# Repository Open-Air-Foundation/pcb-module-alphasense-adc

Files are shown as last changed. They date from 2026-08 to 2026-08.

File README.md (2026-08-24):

# AirGradient AlphaSense ADC Module — Hardware

> KiCad hardware design files for the AirGradient AlphaSense ADC module — the interface board that digitizes the AlphaSense electrochemical gas sensors in the [Open Air Max](https://www.airgradient.com/professional/products/open-air-max/) outdoor air quality monitor.

## Overview

A compact 2-layer board carrying two Texas Instruments ADS1115 16-bit ADCs that read the AlphaSense electrochemical sensors — NO₂ (A43F) and O₃ (A431) — and report to the host monitor over I²C. The supply is filtered through a ferrite bead for clean analog readings.

## Design structure

A single KiCad project in `alphasense-adc/`: one schematic sheet and a 2-layer board. (The project was originally named "ADS1115 for AlphaSense NO2-O3", published on Bitbucket as `alphasense-oa-pcb`, and renamed `alphasense-adc` here; the Gerber filenames inside the archived production zip keep the `alphasense-oa-pcb` naming.)

## Repository structure

```
alphasense-adc/           # KiCad project (schematic + board), production/
libraries/                   # Bundled 3D model libraries
```

## Key components

| Function | Part | Ref |
|---|---|---|
| 16-bit I²C ADC | TI ADS1115IDGSR | U1–U2 |
| Supply filter (ferrite bead) | MMZ2012Y152BT000 | FB1 |
| Host connector (1.25 mm, 8-pin) | Molex 53261-0871 | J1, CN1 |
| Sensor header (2×5 IDC, 2.54 mm) | AWHW2-10G | J2 |

## Toolchain

- **KiCad 9** (file format 2024-12). Symbols and footprints are embedded in the design files; bundled 3D models are referenced project-relative — the project opens without any extra library setup.
- **[Fabrication Toolkit](https://github.com/bennymeg/Fabrication-Toolkit)** plugin — generates the Gerber/BOM/CPL production set in JLCPCB-compatible format.
- Active DRC rules are in `alphasense-adc/alphasense-adc.kicad_dru`.

## Fabrication

`alphasense-adc/production/` holds the ready-to-order set: Gerber zip, BOM, designators, and pick-and-place positions (generated with Fabrication Toolkit, LCSC part numbers for assembly at JLCPCB).

## Versioning & releases

Hardware revisions are tagged on this repository. Per-version release notes and the matching production file set are published on the [GitHub Releases](../../releases) page.

## License

This is open-source hardware. The design files in this repository are licensed under the
[Creative Commons Attribution-ShareAlike 4.0 International (CC BY-SA 4.0)](https://creativecommons.org/licenses/by-sa/4.0/) license — see [LICENSE](LICENSE).

You are free to use, modify, and manufacture these designs, including commercially, provided you credit AirGradient and share derivative designs under the same license.

## Maintainers

AirGradient hardware team.

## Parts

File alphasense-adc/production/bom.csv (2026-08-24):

Designator | Footprint | Quantity | Value | LCSC Part #
C1, C2 | CAPC1608X90N | 2 | CL10B105KP8NNNC
CN1 | CONN-SMD_532610871 | 1 | 532610871 | C293349
FB1 | BEADC2012X105N | 1 | MMZ2012Y152BT000
J2 | AWHW210G0202TR | 1 | AWHW2-10G-0202-T-R
R3, R8 | RESC1608X55N | 2 | 10K
R4, R5, R6, R7 | RESC1608X55N | 4 | 1K
U1, U2 | SOP50P490X110-10N | 2 | ADS1115IDGSR

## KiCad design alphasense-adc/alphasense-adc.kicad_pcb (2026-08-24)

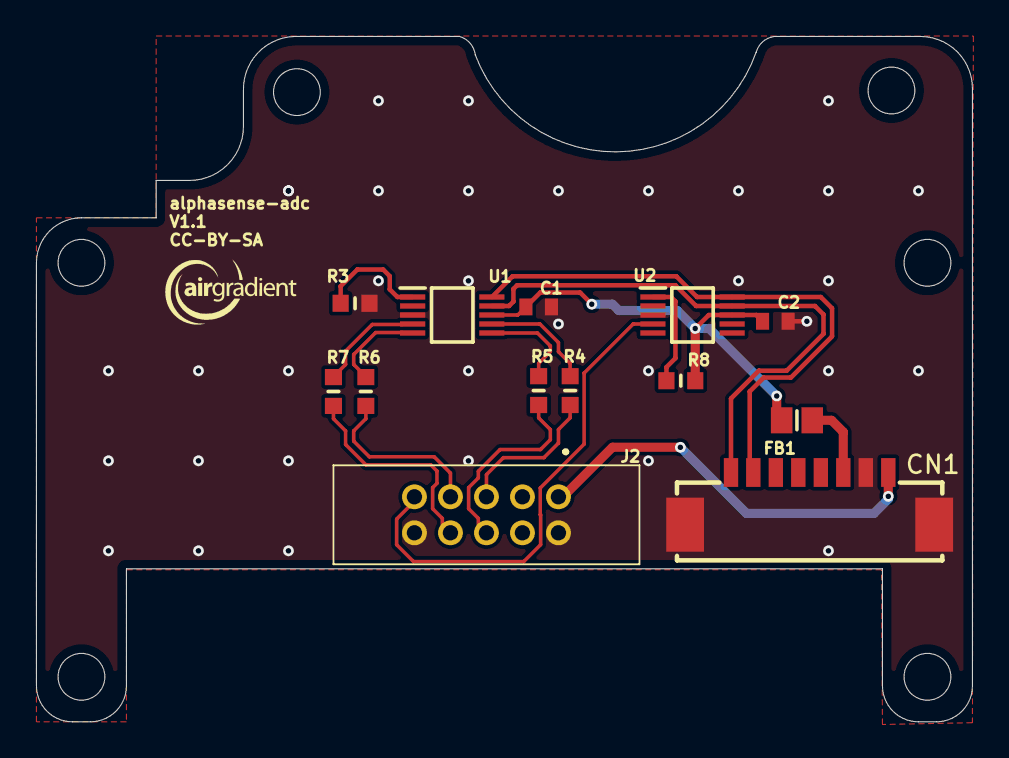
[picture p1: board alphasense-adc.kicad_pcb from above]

Board: 2 copper layers, 52.0 x 38.1 mm, 13 parts (0 on the bottom side), 17 nets.

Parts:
C1, C2: CL10B105KP8NNNC; CAPC1608X90N
CN1: 532610871; CONN-SMD_532610871
FB1: MMZ2012Y152BT000; BEADC2012X105N
J2: AWHW2-10G-0202-T-R; AWHW210G0202TR
R3, R8: 10K; RESC1608X55N
R4, R5, R6, R7: 1K; RESC1608X55N
U1, U2: ADS1115IDGSR; SOP50P490X110-10N

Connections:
3V3: C1.1, C2.1, FB1.2, R8.1, U1.8 (VDD), U2.8 (VDD)
5V: CN1.8, J2.1
+3.3V: CN1.6, FB1.1
/PT1000: J2.9, U2.4 (AIN0)
/SCL: CN1.2, U1.10 (SCL), U2.10 (SCL)
/SDA: CN1.1, U1.9 (SDA), U2.9 (SDA)
/SN1+: J2.8, R7.2
/SN1-: J2.7, R6.2
/SN1_N: R6.1, U1.5 (AIN1)
/SN1_P: R7.1, U1.4 (AIN0)
/SN2+: J2.6, R5.1
/SN2-: J2.5, R4.2
/SN2_N: R4.1, U1.7 (AIN3)
/SN2_P: R5.2, U1.6 (AIN2)
GND: C1.2, C2.2, CN1.0, CN1.7, J2.2, J2.10, R3.2, U1.3 (GND), U2.3 (GND)
unnamed: R3.1, U1.1 (ADDR)
unnamed: R8.2, U2.1 (ADDR)
